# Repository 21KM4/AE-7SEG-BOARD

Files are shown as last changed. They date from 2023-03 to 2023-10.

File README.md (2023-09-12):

# AE-7SEG-BOARD

７セグメントＬＥＤシリアルドライバキット

パラレル出力の抵抗は220Ωです。供給電圧や必要な光度に応じて調整してください。3.3V駆動ならちょうど良い明るさですが、5V駆動の場合は明るすぎると思います。
また、3.3Vでも緑色だと目がおかしくなるほどほど明るくなるので注意。予め7セグを買ってどの抵抗値がちょうどよいかは確認しておくと良いでしょう。

JLCPCB用のガーバーと部品配置もあります

参考にした製品：https://akizukidenshi.com/catalog/g/gK-10194/

上の製品とほぼ同じ回路で、抵抗値だけ変えています。この製品買うより自作して発注した方が安く済んじゃうので...

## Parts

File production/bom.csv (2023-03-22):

Designator | Footprint | Quantity | Value | LCSC Part #
C1 | 0402 | 1 | 100nF | C1525
R1, R2, R3, R4, R5, R6, R7, R8 | 0402 | 8 | 220Ω | C25091
R10, R11, R9 | 0402 | 3 | 10KΩ | C25744
U1 | SOIC-16_3.9x9.9mm_P1.27mm | 1 | 74HC595D, 118 | C5947

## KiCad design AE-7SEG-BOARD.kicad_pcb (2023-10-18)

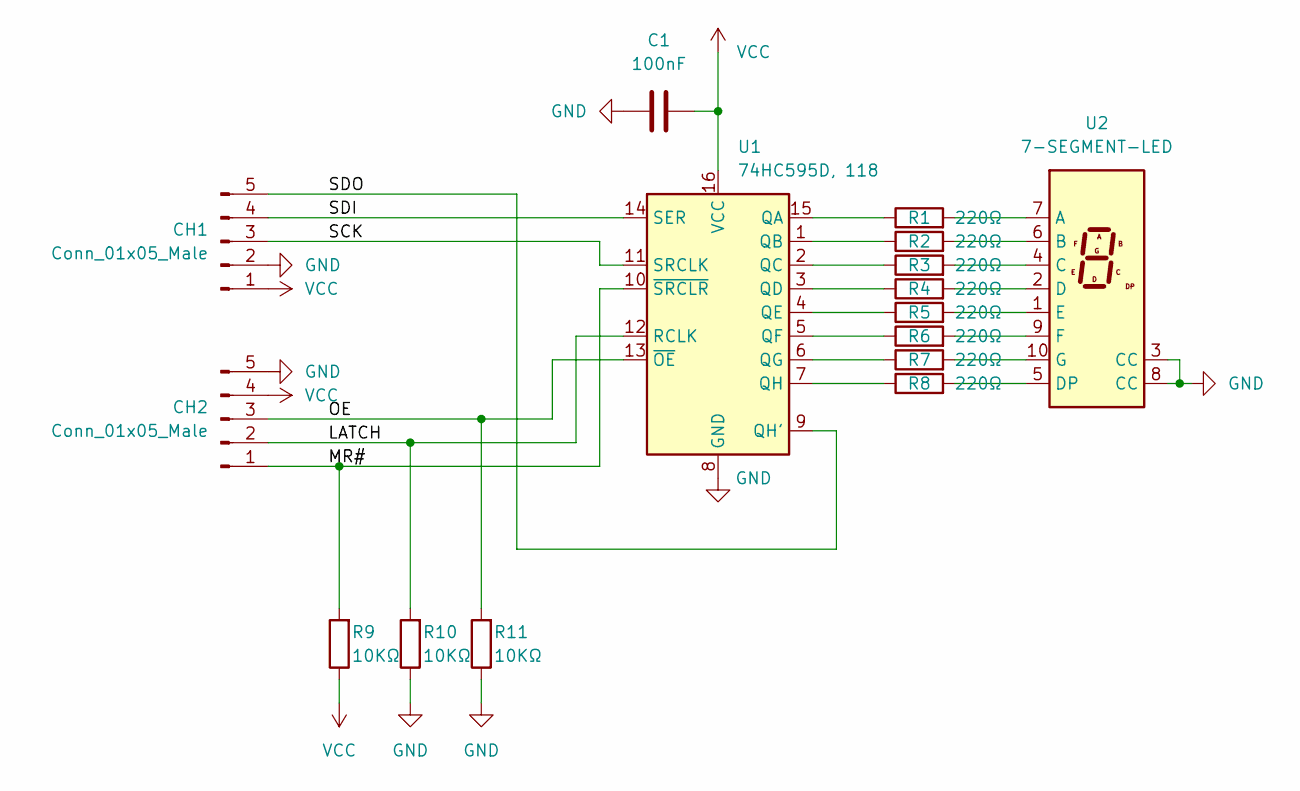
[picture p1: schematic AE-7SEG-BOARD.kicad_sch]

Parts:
C1: 100nF; C_0402_1005Metric; LCSC C1525
CH1, CH2: Conn_01x05_Male; PinHeader_1x05_P2.54mm_Vertical
R1, R2, R3, R4, R5, R6, R7, R8: 220Ω; R_0402_1005Metric; LCSC C25091
R9, R10, R11: 10KΩ; R_0402_1005Metric; LCSC C25744
U1: 74HC595D, 118; SOIC-16_3.9x9.9mm_P1.27mm; LCSC C5947
U2: 7-SEGMENT-LED; D1X8K

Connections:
/LATCH: CH2.2, R10.2, U1.12 (RCLK)
/MR#: CH2.1, R9.2, U1.10 (~SRCLR)
/OE: CH2.3, R11.2, U1.13 (~OE)
/SCK: CH1.3, U1.11 (SRCLK)
/SDI: CH1.4, U1.14 (SER)
/SDO: CH1.5, U1.9 (QH')
GND: C1.1, CH1.2, CH2.5, R10.1, R11.1, U1.8 (GND), U2.3 (CC), U2.8 (CC)
unnamed: R1.1, U1.15 (QA)
unnamed: R2.1, U1.1 (QB)
unnamed: R3.1, U1.2 (QC)
unnamed: R4.1, U1.3 (QD)
unnamed: R5.1, U1.4 (QE)
unnamed: R6.1, U1.5 (QF)
unnamed: R7.1, U1.6 (QG)
unnamed: R8.1, U1.7 (QH)
unnamed: R1.2, U2.7 (A)
unnamed: R2.2, U2.6 (B)
unnamed: R3.2, U2.4 (C)
unnamed: R4.2, U2.2 (D)
unnamed: R8.2, U2.5 (DP)
unnamed: R5.2, U2.1 (E)
unnamed: R6.2, U2.9 (F)
unnamed: R7.2, U2.10 (G)
VCC: C1.2, CH1.1, CH2.4, R9.1, U1.16 (VCC)

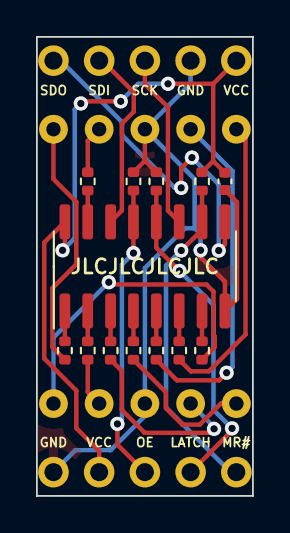
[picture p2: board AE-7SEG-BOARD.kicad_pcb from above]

Board: 2 copper layers, 12.0 x 25.5 mm, 16 parts (1 on the bottom side), 24 nets.
